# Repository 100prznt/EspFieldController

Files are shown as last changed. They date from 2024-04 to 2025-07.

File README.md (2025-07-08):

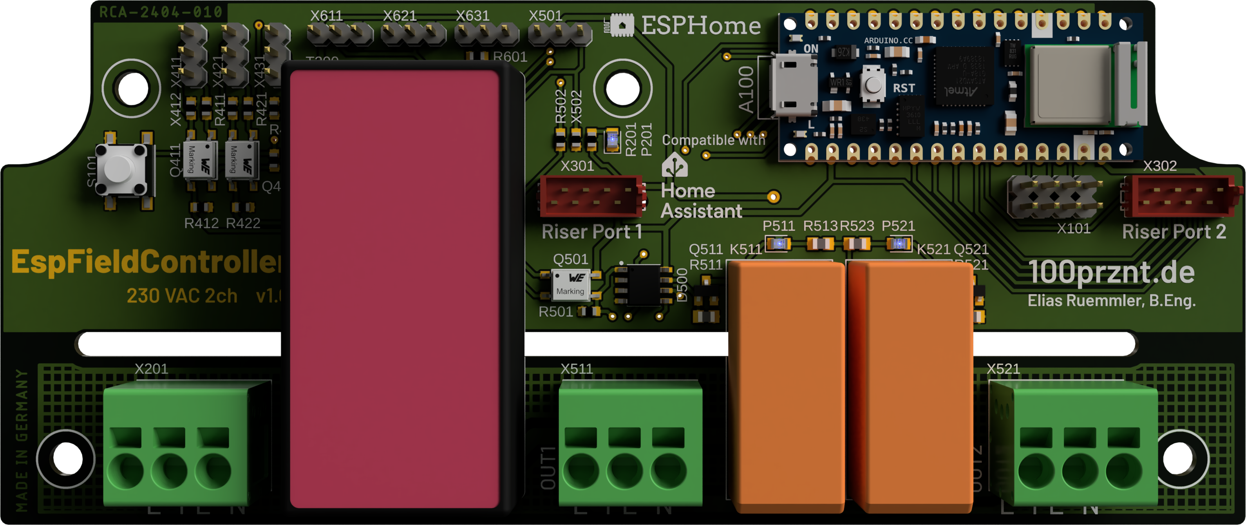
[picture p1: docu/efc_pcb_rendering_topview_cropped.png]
CAD rendering EspFieldController PCB


# ESP Field Controller
Modular aufgebauter Hardware-Controller für den Betrieb mit ESPHome.

Mit dem **ESP Field Controller** möchte ich eine Hardwarebasis für den Einsatz von ESPHome im "Außenbereich", also zumindest außerhab von Wohnräumen, schaffen. Eine wichtige Anforderung ist hier natürlich die [Schutzart](https://de.wikipedia.org/wiki/Schutzart). Daher wird der Controller in ein entsprechnd klassifiziertes Gehäuse montiert und verfügt auch über ein eigenes Netzteil. Basisfunktionalität, welche sehr oft benötigt wird, bringt der Controller selber mit. Für Anwendungen, welche etwas speziellere Features benötigen, lässt sich der Controller modular erweitern.

## Projektstatus
Nach einem ersten Prototyp-Aufbau auf dem Breadboard, folgt nun die erste PCB Revision. Hier ein fertiger **EspFieldController** mit gebrückter *Safety Circuit* und [WaterAnalyticRiser](WaterAnalyticRiser) *(WAR)*.

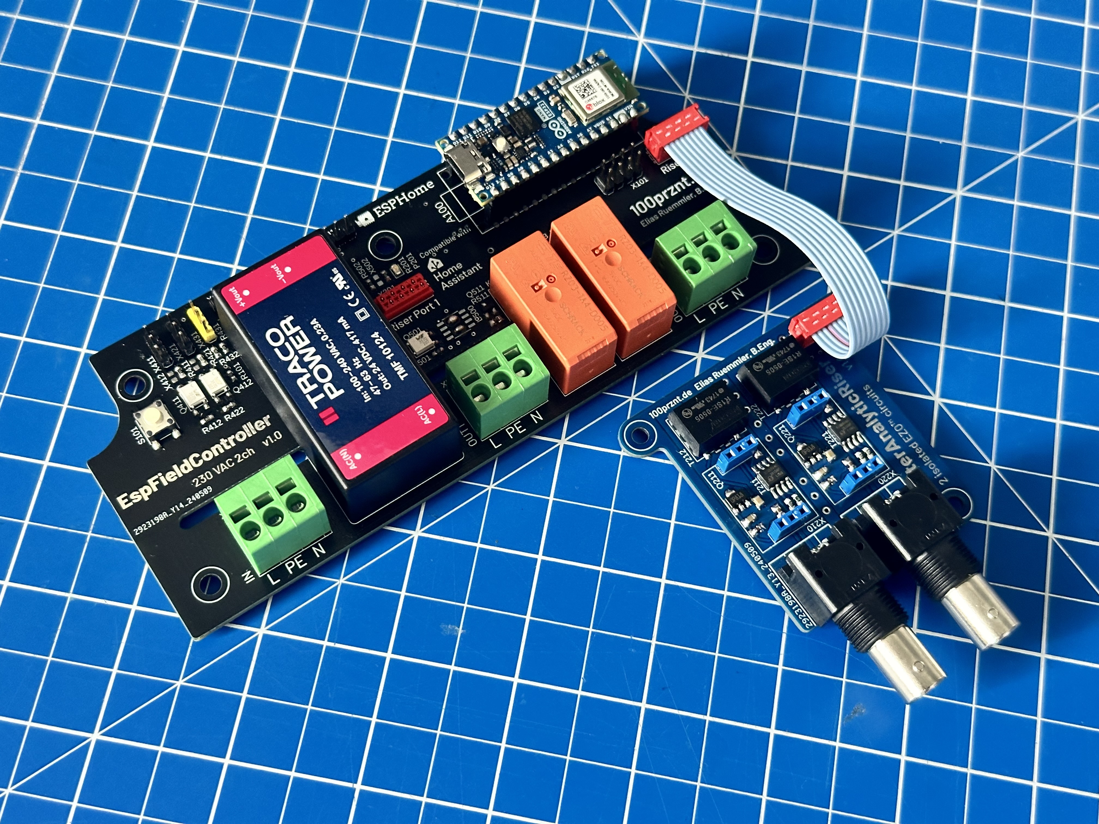
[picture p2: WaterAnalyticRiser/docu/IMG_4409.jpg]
Aufgebauter EspFieldController mit Water Analytic Riser


## Basisfunktionen

### Netzteil
* 230 VAC Netzklemme
* Versorgung von Arduino Nano ESP32 und Peripherie
* 5 VDC (VIN)
#### Auf Arduino Nano ESP32
* Schutzdiode zwischen USB und VIN
* 3,3 VDC über linearen Spannungsregler

### Eingänge
* 2 digitale Eingänge, per Optokoppler Isoliert (Spannung kann über Widerstandsnetzwerk individuell festgelegt werden)
* 1 digitaler Freigabeeingang für Safety Circuit, per Optokoppler Isoliert (Spannung kann über Widerstandsnetzwerk individuell festgelegt werden)
* 1 analoger Eingang (Spannungsbereich kann über Widerstandsnetzwerk individuell festgelegt werden)
* 1 Taster

### Ausgänge

#### Relais
* 2 unabhängige Kanäle
* 230 VAC 10 A (einpolig, Summenstrom nicht über 10 A)
* 230 VAC Eingang über Netzklemme, L, N, PE (welche auch das Netzteil versorgt)
* Ausgangsklemmen inkl. N und PE
##### Safety Circuit
* Optional per eigenen Controller (alternativ per 0R gebrückt)
* ATtiny25 (SOIC)
* Softwarefunktionen
  * Überwachung des ESP per Watchdog
  * Externe Freigabe per Enable Eingang (isoliert)
  * Verriegelung der Kanäle (inkl. Definition von Umschaltzeiten)
 
###### Pinning
| Pin | Port | ATtiny25 | Funktion |
|-----|---|---|---|
| 1 | PB5  | PCINT5/RESET/ADC0/dW | Ext. Enable |
| 2 | PB3  | PCINT3/XTAL1/CLKI/OC1B/ADC3 | Ch1 Enable  |
| 3 | PB4  | PCINT4/XTAL2/CLKO/OC1B/ADC2 | Ch2 Enable  |
| 4 | GND  | | |
| 5 | PB0  | MOSI/DI/SDA/AIN0/OC0A/OC1A/AREF/PCINT0 | Watchdog |
| 6 | PB1  | MISO/DO/AIN1/OC0B/OC1A/PCINT1 | Ch2 Out |
| 7 | PB2  | SCK/USCK/SCL/ADC1/T0/INT0/PCINT2 | Ch1 Out |
| 8 | VCC  | | |

### 1-Wire
* 3 Stecker auf einem Bus (2,54 mm Stiftleiste)

## Riser
Zur modularen Erweiterung können an den _EspFiledController_ bis zu zwei _Riser Boards_ angeschlossen werden.
* [WAR - Water Analytic Riser](/WaterAnalyticRiser)
* [LCR - LoadCellRiser](/LoadCellRiser)

### Riser-Ports

#### Pinning Micro-Match
| Pin | | Funktion | GPIO |
|-----|---|---|---|
| 1  | Supply | +5 V | |
| 2  | Supply | +3.3 V | |
| 3  | IO | EXT1_IO1 | |
| 4  | IO | EXT2_IO2 | |
| 5  | I2C | SDA | GPIO11 |
| 6  | I2C | SCL | GPIO12 |
| 7  | 1-Wire | Data | GPIO5  |
| 8  | | GND | |

### ESP Board
* Arduino Nano ESP32 (NORA-W106-10B [ESP32-S3])
* Alternative (low-cost) Boards per individueller PCB (mapping auf Nano Footprint) 

#### Pinning
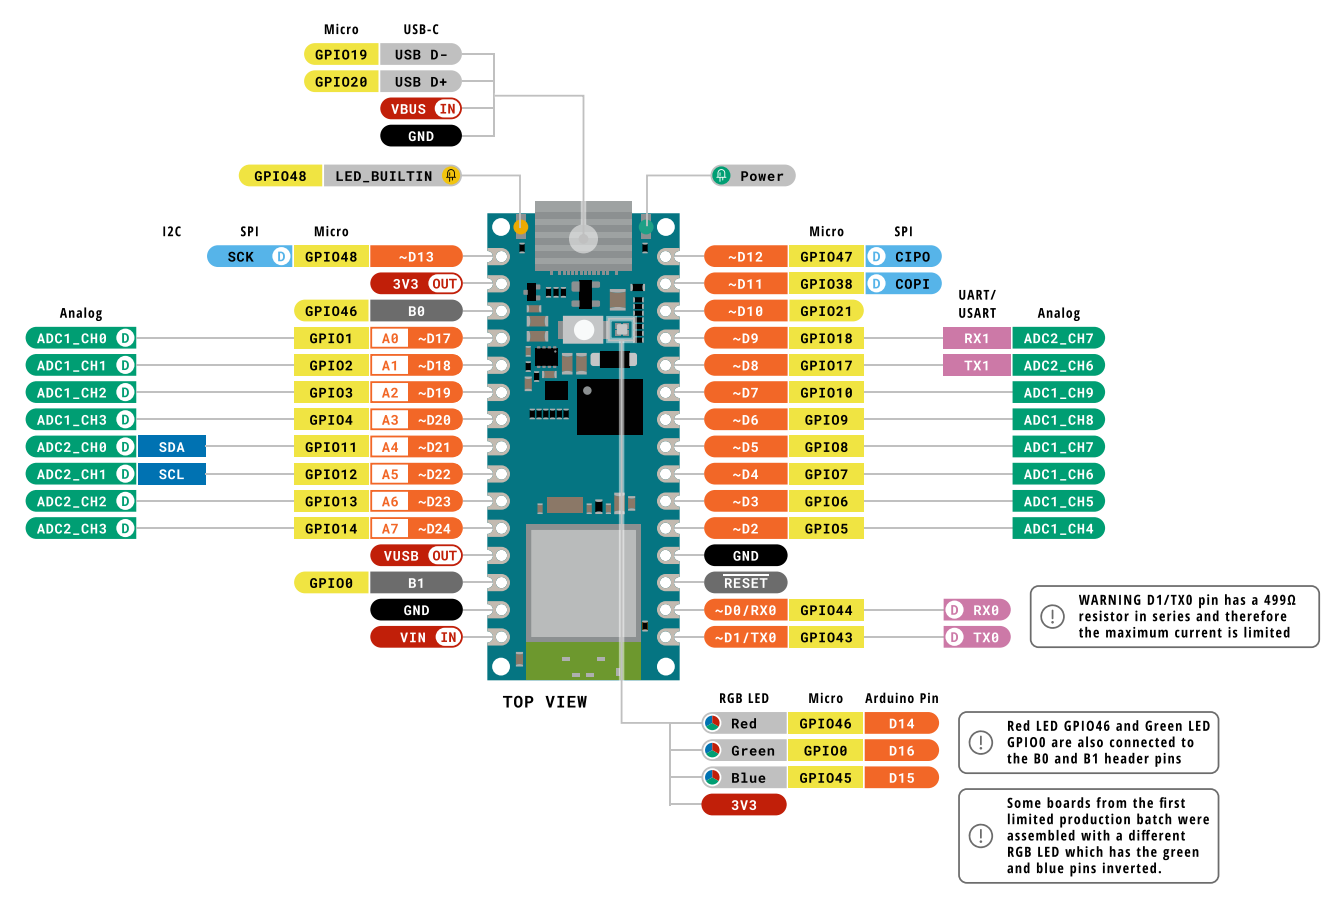
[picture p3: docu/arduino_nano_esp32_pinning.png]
Pinning Arduino Nano ESP32


## GPIO Zuordnung
| GPIO | Funktion | Funktionseinheit | Beschreibung |
|---|---|---|---|
| 0 | LED green | | |
| 1 | | EXT1 | |
| 2 | | EXT1 | |
| 3 | | EXT2 | |
| 4 | | EXT2 | |
| 5 | | 1-Wire | |
| 6 | | Taster | |
| 7 | | Relais | IN EN |
| 8 | | Relais | OUT Watchdog |
| 9 | | Relais | OUT CH1 |
| 10 | | Relais | OUT CH2 |
| 11 | I2C SDA | EXT1 u. EXT2 | |
| 12 | I2C SCL | EXT1 u. EXT2 | |
| 13 | | Eingang | |
| 14 | | Eingang | |
| 17 | | Analogeingang | |
| 18 | | | |
| 21 | | | |
| 38 | SPI COPI | | |
| 43 | UART RX0 | | |
| 44 | UART TX0 | | |
| 45 | LED blue | | |
| 46 | LED red | | |
| 47 | SPI CIPO | | |
| 48 | SPI SCK; LED_BUILDIN | | |

#### Standardpins
| ~D | GPIO | I2C | SPI |
|----|---|-----|---|
| 21 | 11 | SDA | |
| 22 | 12 | SCL | |
| 10 | 21 | | CS |
| 11 | 38 | | COPI (MOSI) |
| 12 | 47 | | CIPO (MISO) |
| 13 | 48 | | SCK |

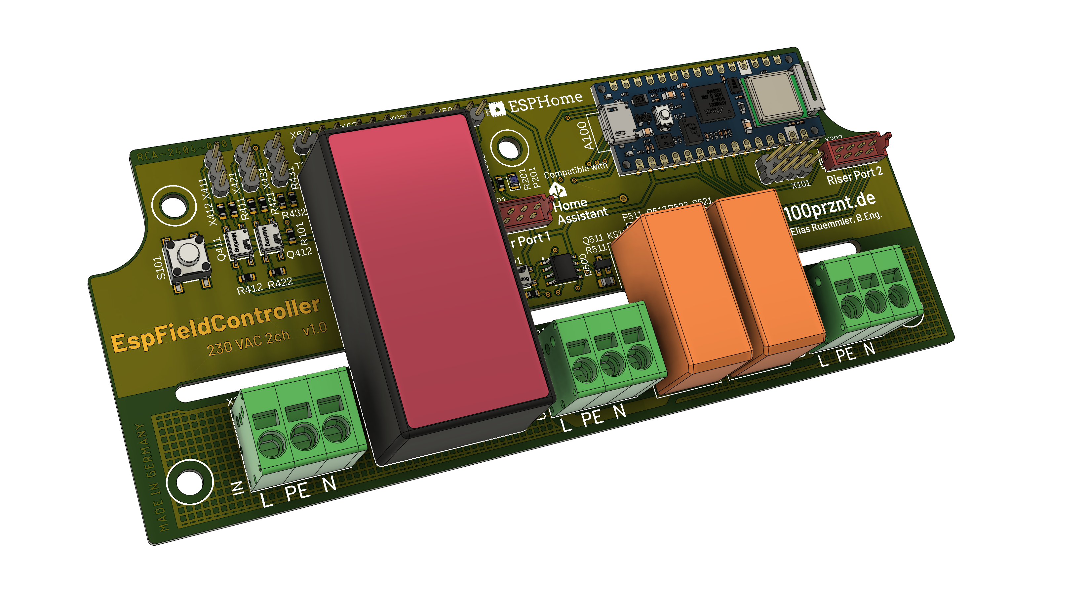
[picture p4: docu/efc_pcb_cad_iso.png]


## Feature Request (next version)
* Relais überwachen
  - Stromüberwachung
  - Sicherheitsrelais
* Rückmeldung Safety Cricuit an ESP

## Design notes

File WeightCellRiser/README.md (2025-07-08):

# Load Cell Riser :mag:

Erweitert den [ESP Field Controller](../) um zwei NAU7802 24-bit ADCs, an welche Wägezellen oder -sensoren angeschlossen werden können.

### NAU7802
Adafruit - NAU7802 24-bit ADC

* [ESPHome - NAU7802](https://esphome.io/components/sensor/nau7802)
* [I2C Mux](https://esphome.io/components/tca9548a)

### Notes
* [SparkFun - Load Cell Amplifier HX711 Breakout Hookup Guide](https://learn.sparkfun.com/tutorials/load-cell-amplifier-hx711-breakout-hookup-guide)
* [SparkFun - Load Cell Combinator - Schematics](https://cdn.sparkfun.com/datasheets/Sensors/ForceFlex/SparkFun%20Load%20Sensor%20Combinator%20v11.pdf)

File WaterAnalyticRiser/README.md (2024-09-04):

# Water Analytic Riser :sweat_drops:

Erweitert den [ESP Field Controller](../) um zwei EZO Circuit Sockel, welche die entsprechenden Module von Atlas Scientifics aufnehmen können.

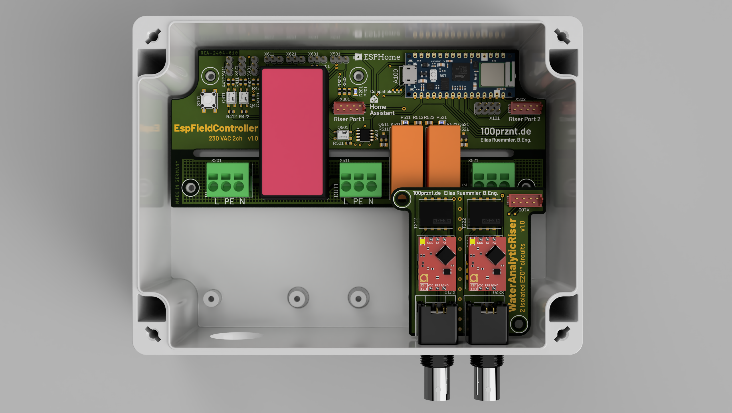
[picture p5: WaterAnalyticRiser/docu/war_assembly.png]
Zusammenbau im Spelsberg Gehäuse

_Der Water Analytic Riser findet zusammen mit dem ESP Field Controller im Spelsberg Industriegehäuse platz._

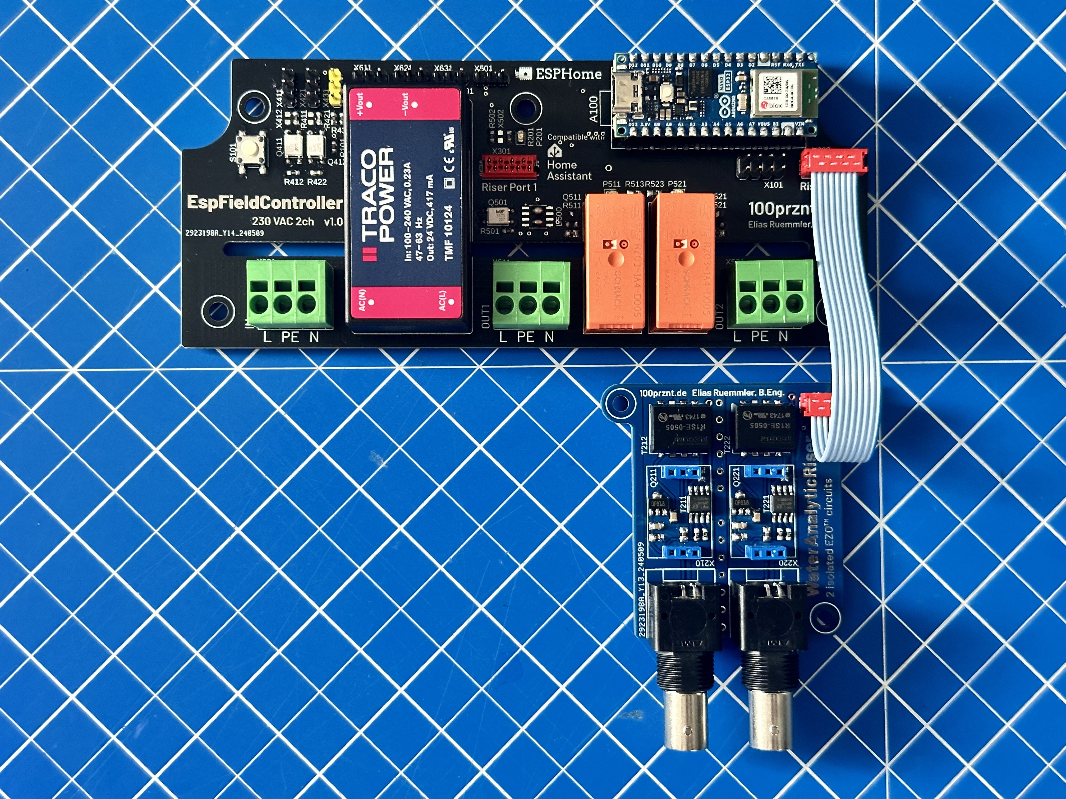
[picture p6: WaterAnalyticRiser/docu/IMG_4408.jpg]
Aufgebauter EspFieldController mit Water Analytic Riser


## Anwendung

Die Idee hinter dem __Water Analytic Riser__ ist der Aufbau einer automatischen Pool-Dosiersteuerung. Hierzu ist es erforderlich den __pH-Wert__ sowie das __Redoxpotential__ (ORP) messtechnisch zu erfassen und entsprechende __Dosierpumpen__ für Schwefelsäure (pH Senker) bzw. Natriumhypochlorit (Chlor) anzusteueren.
Über die ESPHome Konfiguration kann eine einfache Regelung eingerichtet werden, sodass die Dosierung der Chemie automatisch erfolgt und auch keine Host-Verbindung (Verbindung zu Home Assistant) erforderlich ist. Die entsprechenden Vorgabe- und Einstellwerte werden über Home Assistant konfiguriert und die Messwerte überwacht.

### Externe Hardware
* pH Elektrode
* Redox Elektrode
* Temperaturfühler (DS18B20) :link:
* Dosierpumpe für pH Senker :link:
* Dosierpumpe für Chlor :link:

:link: Anschluss am __ESP Field Controller__

## Funktionen

Um eine Potentialverschiebung an den eingesetzen Messelektroden zu vermeiden, ist sowohl die Versorgungsspannung als auch der I2C Bus für jedes EZO Circuit isoliert ausgeführt. Die herausgeführten Elektrodenanschlüsse sind somit gegeneinander und gegen den ESP Field Controller isoliert, sowohl auf der Messleitung also auch auf der zugehörigen Masse.

* Isolierte Versorgungsspannung je EZO Sockel
* Isolierter I2C Bus je EZO Sockel

## Feature Request

* 1-Wire Stecker für DS18B20
* Taster für Kalibrierung
* Linear geregelte Spannungsversorgung (low noise)
* Versorgunsspannung schaltbar (stand-by)

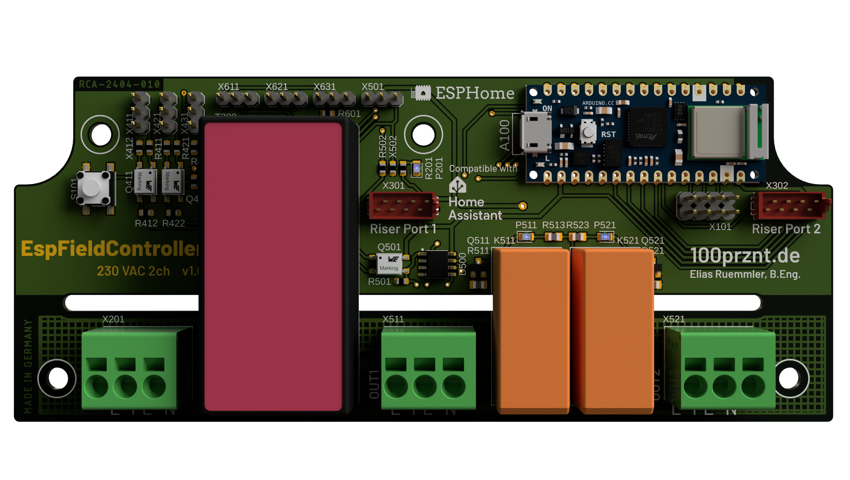
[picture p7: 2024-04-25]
docu/efc_pcb_rendering_topview.png

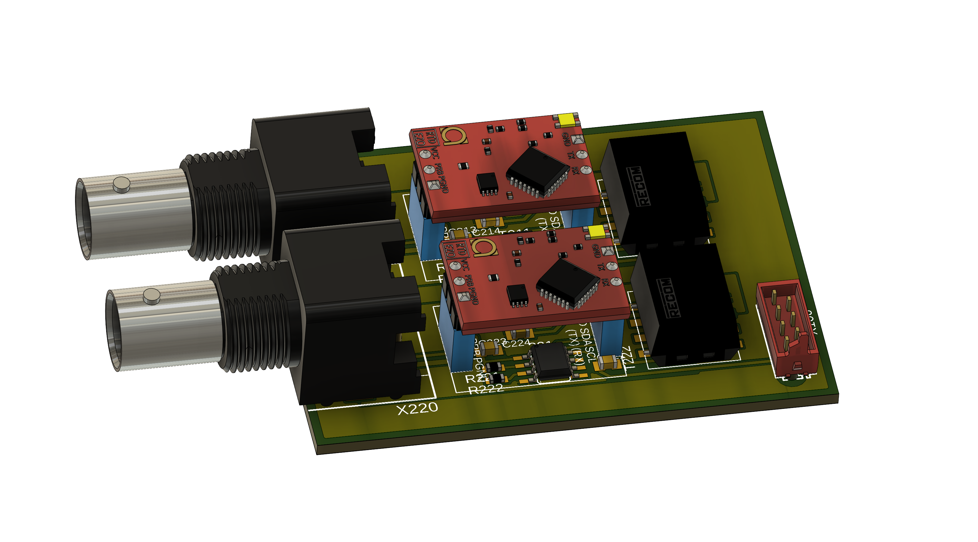
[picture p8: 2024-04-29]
WaterAnalyticRiser/docu/war_pcb_cad_iso_beta.png

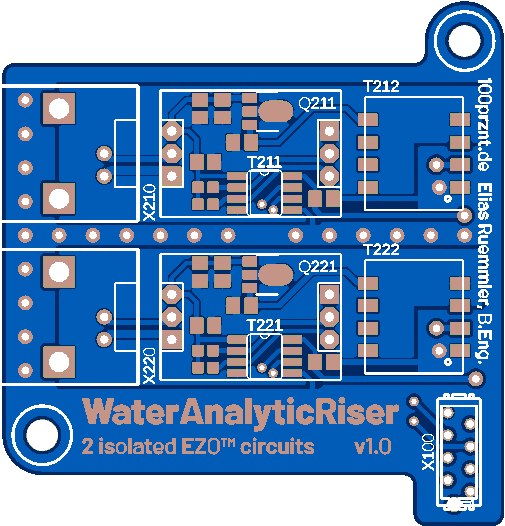
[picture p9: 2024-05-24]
WaterAnalyticRiser/production/JLCPCB_GerberView.png

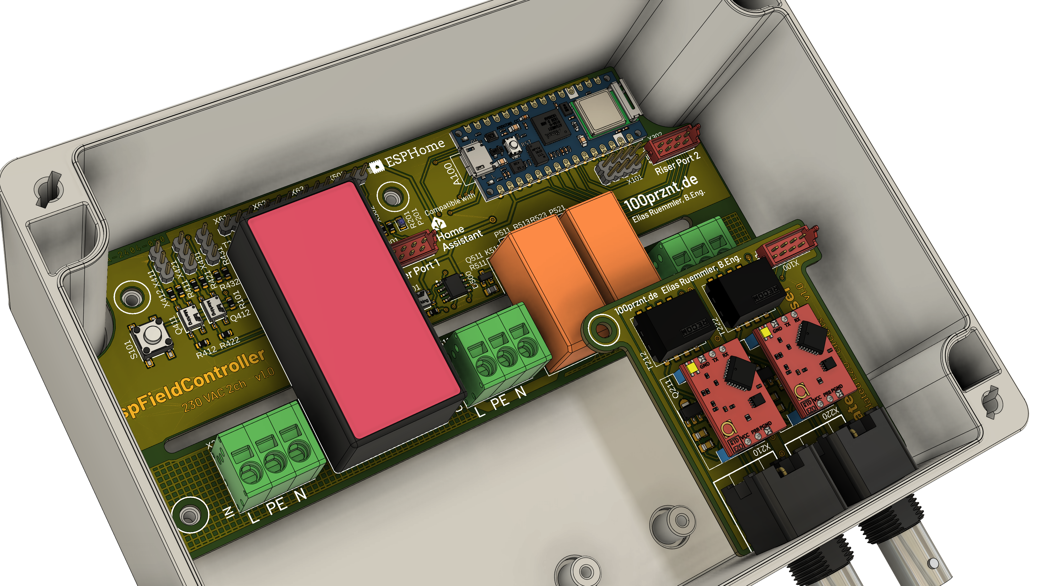
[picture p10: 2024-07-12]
WaterAnalyticRiser/docu/war_asy_cad_iso.png

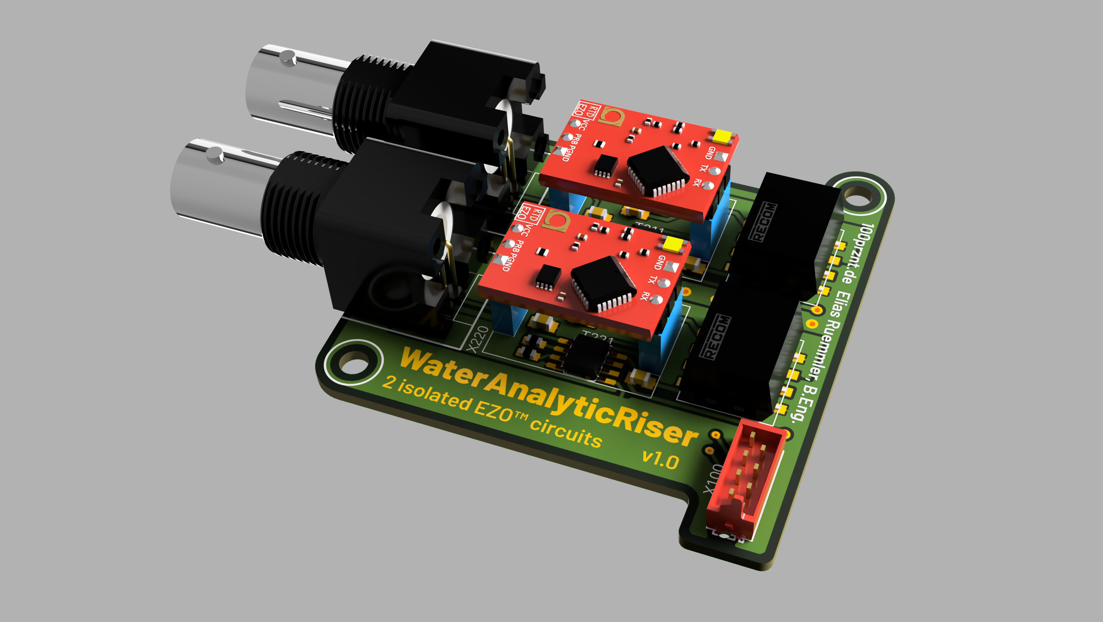
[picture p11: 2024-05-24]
WaterAnalyticRiser/docu/war_pcb_redering_iso.png

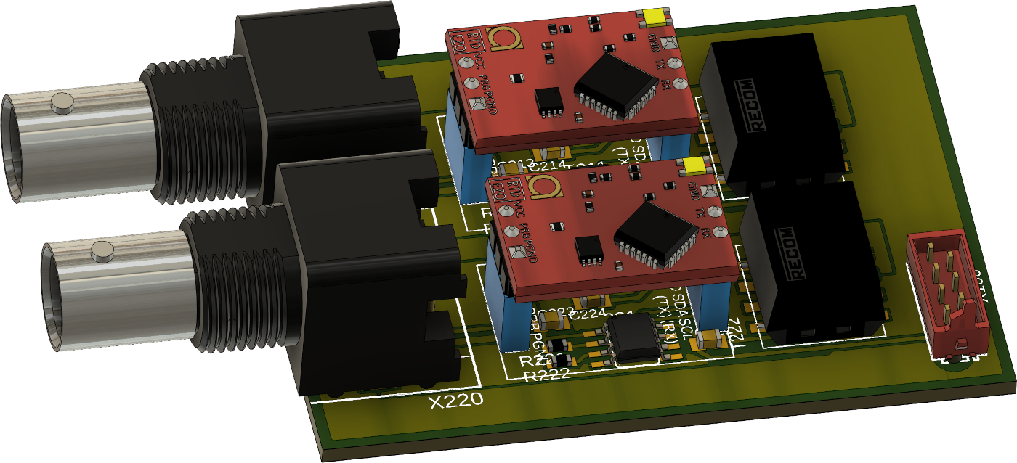
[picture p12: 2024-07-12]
WaterAnalyticRiser/docu/war_pcb_cad_iso_beta_cropped_resized.png

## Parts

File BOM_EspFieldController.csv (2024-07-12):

Part | Value | Device | Package | Description | ARROW_PART_NUMBER | ARROW_PRICE-STOCK | BUILT_BY | CATEGORY | COLOR | COPYRIGHT | CORE | CTR-MAX | CTR-MIN | DATASHEET-URL | DESCRIPTION | DRAIN_CURRENT | FORWARD_CURRENT | HEIGHT | IF | MANUFACTURER | MANUFACTURER_NAME | MANUFACTURER_PART_NUMBER | MF | MOUNT | MOUSER_PART_NUMBER | MOUSER_PRICE-STOCK | MPN | OC_FARNELL | OC_NEWARK | OPERATING_TEMP | OPERATION-FORCE | PART-NUMBER | PART_STATUS | POPULARITY | QTY | REVERSE_VOLTAGE | ROHS_COMPLIANT | SERIES | SPEED | SPICEPREFIX | SUB-CATEGORY | TC-CTR | THERMALLOSS | TYPE | VALUE | VCE | VENDOR | VISO
A100 | Arduino Nano ESP32 | NANO_ESP32 | NANO |  |  |  |  |  |  |  |  |  |  |  |  |  |  |  |  |  |  |  |  |  |  |  |  |  |  |  |  |  |  |  |  |  |  |  |  |  |  |  |  |  | Arduino Nano ESP32
D500 | ATtiny25-20SSH | ATTINY25-20SSH-8PIN_SOIC | SOIC127P600X175-8N | Atmel tiny25/45/85, 8-bit AVR Microcontroller with 2/4/8K |  |  |  | IC_Embedded |  |  | AVR |  |  |  | AVR AVR� ATtiny, Functional Safety (FuSa) Microcontroller IC 8-Bit 20MHz 2KB (1K x 16) FLASH 8-SOIC |  |  |  |  | Microchip Technology |  |  |  |  |  |  | ATtiny25-20SSH |  |  | -40�C to 85�C |  |  | Active |  |  |  | COMPLIANT | ATtiny25 | 20 MHz |  | Microcontroller |  |  | 8 bit Microcontroller | ATtiny25-20SSH
K511 | RZ03-1A4-D005 | 1-1415899-6 | RELAY-SPST2_5MM |  |  |  | EMA_UL_Team | Power Relays |  | Copyright (C) 2016 Accelerated Designs. All rights reserved |  |  |  |  | RZ03-1A4-D012 |  |  |  |  |  |  | 1-1415899-6 |  |  |  |  |  |  |  |  |  |  | active |  |  |  |  | SCHRACK Power PCB Relay RZ |  |  |  |  |  |  |  |  | TE Connectivity
K521 | RZ03-1A4-D005 | 1-1415899-6 | RELAY-SPST2_5MM |  |  |  | EMA_UL_Team | Power Relays |  | Copyright (C) 2016 Accelerated Designs. All rights reserved |  |  |  |  | RZ03-1A4-D012 |  |  |  |  |  |  | 1-1415899-6 |  |  |  |  |  |  |  |  |  |  | active |  |  |  |  | SCHRACK Power PCB Relay RZ |  |  |  |  |  |  |  |  | TE Connectivity
P201 | LED_BLUE | CHIP-FLAT-B_0805 | LEDC2012X110N_FLAT-B |  |  |  |  | LED | BLUE |  |  |  |  |  | CHIP LED FLAT |  |  |  |  |  |  |  |  |  |  |  |  |  |  |  |  |  |  |  |  |  |  |  |  |  | CHIP |  |  | FLAT_TOP | LED_BLUE
P511 | LED_BLUE | CHIP-FLAT-B_0805 | LEDC2012X110N_FLAT-B |  |  |  |  | LED | BLUE |  |  |  |  |  | CHIP LED FLAT |  |  |  |  |  |  |  |  |  |  |  |  |  |  |  |  |  |  |  |  |  |  |  |  |  | CHIP |  |  | FLAT_TOP | LED_BLUE
P521 | LED_BLUE | CHIP-FLAT-B_0805 | LEDC2012X110N_FLAT-B |  |  |  |  | LED | BLUE |  |  |  |  |  | CHIP LED FLAT |  |  |  |  |  |  |  |  |  |  |  |  |  |  |  |  |  |  |  |  |  |  |  |  |  | CHIP |  |  | FLAT_TOP | LED_BLUE
Q411 | 140357145400 | WL-OCPT_SERIES_357_140357145400 | WL-OCPT_SOP4 | WL-OCPT SOP-4 |  |  |  |  |  |  |  | 600% | 300% | https://www.we-online.com/redexpert/spec/140357145400?ae |  |  |  |  | 60mA |  |  |  |  | SMT |  |  |  |  |  |  |  | 140357145400 |  |  |  |  |  |  |  |  |  | IF = 5mA,VCE = 5 V |  |  | 140357145400 | 35V |  | 3750(V(RMS))
Q412 | 140357145400 | WL-OCPT_SERIES_357_140357145400 | WL-OCPT_SOP4 | WL-OCPT SOP-4 |  |  |  |  |  |  |  | 600% | 300% | https://www.we-online.com/redexpert/spec/140357145400?ae |  |  |  |  | 60mA |  |  |  |  | SMT |  |  |  |  |  |  |  | 140357145400 |  |  |  |  |  |  |  |  |  | IF = 5mA,VCE = 5 V |  |  | 140357145400 | 35V |  | 3750(V(RMS))
Q501 | 140357145400 | WL-OCPT_SERIES_357_140357145400 | WL-OCPT_SOP4 | WL-OCPT SOP-4 |  |  |  |  |  |  |  | 600% | 300% | https://www.we-online.com/redexpert/spec/140357145400?ae |  |  |  |  | 60mA |  |  |  |  | SMT |  |  |  |  |  |  |  | 140357145400 |  |  |  |  |  |  |  |  |  | IF = 5mA,VCE = 5 V |  |  | 140357145400 | 35V |  | 3750(V(RMS))
Q511 | BSS138 | NMOSFETSOT23-GSD | SOT23 | N-Channel MOSFET - Generic |  |  |  | Transistor |  |  |  |  |  |  |  |  |  |  |  |  |  |  |  |  |  |  |  |  |  |  |  |  |  |  |  |  |  |  |  |  | MOSFET |  |  | N-Channel | NMOSFET
Q521 | BSS138 | NMOSFETSOT23-GSD | SOT23 | N-Channel MOSFET - Generic |  |  |  | Transistor |  |  |  |  |  |  |  |  |  |  |  |  |  |  |  |  |  |  |  |  |  |  |  |  |  |  |  |  |  |  |  |  | MOSFET |  |  | N-Channel | NMOSFET
R101 | 10K | R-EU_R0603 | R0603 | RESISTOR, European symbol |  |  |  |  |  |  |  |  |  |  |  |  |  |  |  |  |  |  |  |  |  |  |  |  |  |  |  |  |  | 70 |  |  |  |  |  | R
R201 | 500R | R-EU_R0603 | R0603 | RESISTOR, European symbol |  |  |  |  |  |  |  |  |  |  |  |  |  |  |  |  |  |  |  |  |  |  |  |  |  |  |  |  |  | 70 |  |  |  |  |  | R
R411 | 500R | R-EU_R0603 | R0603 | RESISTOR, European symbol |  |  |  |  |  |  |  |  |  |  |  |  |  |  |  |  |  |  |  |  |  |  |  |  |  |  |  |  |  | 70 |  |  |  |  |  | R
R412 | 500R | R-EU_R0603 | R0603 | RESISTOR, European symbol |  |  |  |  |  |  |  |  |  |  |  |  |  |  |  |  |  |  |  |  |  |  |  |  |  |  |  |  |  | 70 |  |  |  |  |  | R
R421 | 500R | R-EU_R0603 | R0603 | RESISTOR, European symbol |  |  |  |  |  |  |  |  |  |  |  |  |  |  |  |  |  |  |  |  |  |  |  |  |  |  |  |  |  | 70 |  |  |  |  |  | R
R422 | 500R | R-EU_R0603 | R0603 | RESISTOR, European symbol |  |  |  |  |  |  |  |  |  |  |  |  |  |  |  |  |  |  |  |  |  |  |  |  |  |  |  |  |  | 70 |  |  |  |  |  | R
R431 | 10K | R-EU_R0603 | R0603 | RESISTOR, European symbol |  |  |  |  |  |  |  |  |  |  |  |  |  |  |  |  |  |  |  |  |  |  |  |  |  |  |  |  |  | 70 |  |  |  |  |  | R
R432 | 10K | R-EU_R0603 | R0603 | RESISTOR, European symbol |  |  |  |  |  |  |  |  |  |  |  |  |  |  |  |  |  |  |  |  |  |  |  |  |  |  |  |  |  | 70 |  |  |  |  |  | R
R501 | 220 | R-EU_R0603 | R0603 | RESISTOR, European symbol |  |  |  |  |  |  |  |  |  |  |  |  |  |  |  |  |  |  |  |  |  |  |  |  |  |  |  |  |  | 70 |  |  |  |  |  | R
R502 | 220 | R-EU_R0603 | R0603 | RESISTOR, European symbol |  |  |  |  |  |  |  |  |  |  |  |  |  |  |  |  |  |  |  |  |  |  |  |  |  |  |  |  |  | 70 |  |  |  |  |  | R
R511 | 47K | R-EU_R0805 | R0805 | RESISTOR, European symbol |  |  |  |  |  |  |  |  |  |  |  |  |  |  |  |  |  |  |  |  |  |  |  |  |  |  |  |  |  | 86 |  |  |  |  |  | R
R512 | 1N4148W | DIODE_1N4148W-7-F_SOD123G | SOD3715X135 | Diode Rectifier - Popular parts |  |  |  | Diode |  |  |  |  |  |  | DIODE GEN PURP 100V 300MA SOD123 |  |  |  |  | Diodes Incorporated |  |  |  |  |  |  |  |  |  |  |  |  |  |  |  |  |  |  |  |  | Rectifier |  |  |  | 1N4148W
R513 | 220 | R-EU_R0805 | R0805 | RESISTOR, European symbol |  |  |  |  |  |  |  |  |  |  |  |  |  |  |  |  |  |  |  |  |  |  |  |  |  |  |  |  |  | 86 |  |  |  |  |  | R
R521 | 47K | R-EU_R0805 | R0805 | RESISTOR, European symbol |  |  |  |  |  |  |  |  |  |  |  |  |  |  |  |  |  |  |  |  |  |  |  |  |  |  |  |  |  | 86 |  |  |  |  |  | R
R522 | 1N4148W | DIODE_1N4148W-7-F_SOD123G | SOD3715X135 | Diode Rectifier - Popular parts |  |  |  | Diode |  |  |  |  |  |  | DIODE GEN PURP 100V 300MA SOD123 |  |  |  |  | Diodes Incorporated |  |  |  |  |  |  |  |  |  |  |  |  |  |  |  |  |  |  |  |  | Rectifier |  |  |  | 1N4148W
R523 | 220 | R-EU_R0805 | R0805 | RESISTOR, European symbol |  |  |  |  |  |  |  |  |  |  |  |  |  |  |  |  |  |  |  |  |  |  |  |  |  |  |  |  |  | 86 |  |  |  |  |  | R
R601 | 10K | R-EU_R0603 | R0603 | RESISTOR, European symbol |  |  |  |  |  |  |  |  |  |  |  |  |  |  |  |  |  |  |  |  |  |  |  |  |  |  |  |  |  | 70 |  |  |  |  |  | R
S101 | 430152050826 | 430152050826 | 430152050826 | WS-TASV SMT Tact Switch 6x6 mm |  |  |  |  |  |  |  |  |  | https://www.we-online.com/redexpert/spec/430152050826?ae |  |  |  | 5mm |  |  |  |  |  |  |  |  |  |  |  |  | 260g | 430152050826 |  |  | 1000 |  |  |  |  |  |  |  |  |  | 430152050826
T200 | TMF 10105 | TMF_101 | TMF10
X101 |  | PINHD-2X4 | 2X04 | PIN HEADER |  |  |  |  |  |  |  |  |  |  |  |  |  |  |  |  |  |  |  |  |  |  |  |  |  |  |  |  |  | 47
X201 | SPT2,5/3-V-5,0 | SPT2,5/3-V-5,0 | SPT2,5/3-V-5,0 | SPT 2,5/ 3-V-5,0 | 1991105 | https://www.arrow.com/en/products/1991105/phoenix-contact?region=nac |  |  |  |  |  |  |  |  | PCB terminal block, nominal current: 24 A, rated voltage (III/2): 400 V, nominal cross section: 2.5 mm?, Number of potentials: 3, Number of rows: 1, Number of positions per row: 3, product range: SPT 2,5/..-V, pitch: 5 mm, connection method: Push-in spring connection, mounting: Wave soldering, conductor/PCB connection direction: 90 ?, color: green, Pin layout: Linear double pinning, Solder pin [P]: 2.5 mm, type of packaging: packed in cardboard |  |  | 14.4mm |  |  | Phoenix Contact | 1991105 |  |  | 651-1991105 | https://www.mouser.co.uk/ProductDetail/Phoenix-Contact/1991105?qs=HG6crFoccqodg51MDMYEiw%3D%3D
X301 | MICROMATCH-8 | MICROMATCH-8 | MICROMATCH-8 | MicroMaTch 8 7-215464-8 / 0-215464-8 |  |  |  |  |  |  |  |  |  |  |  |  |  |  |  |  |  |  | FARNELL |  |  |  | 7-215464-8 | 3784642 | 26H0301
X302 | MICROMATCH-8 | MICROMATCH-8 | MICROMATCH-8 | MicroMaTch 8 7-215464-8 / 0-215464-8 |  |  |  |  |  |  |  |  |  |  |  |  |  |  |  |  |  |  | FARNELL |  |  |  | 7-215464-8 | 3784642 | 26H0301
X411 |  | PINHD-1X3 | 1X03 | PIN HEADER |  |  |  |  |  |  |  |  |  |  |  |  |  |  |  |  |  |  |  |  |  |  |  |  |  |  |  |  |  | 92
X412 | n/a | R-EU_R0603 | R0603 | RESISTOR, European symbol |  |  |  |  |  |  |  |  |  |  |  |  |  |  |  |  |  |  |  |  |  |  |  |  |  |  |  |  |  | 70 |  |  |  |  |  | R
X421 |  | PINHD-1X3 | 1X03 | PIN HEADER |  |  |  |  |  |  |  |  |  |  |  |  |  |  |  |  |  |  |  |  |  |  |  |  |  |  |  |  |  | 92
X422 | n/a | R-EU_R0603 | R0603 | RESISTOR, European symbol |  |  |  |  |  |  |  |  |  |  |  |  |  |  |  |  |  |  |  |  |  |  |  |  |  |  |  |  |  | 70 |  |  |  |  |  | R
X431 |  | PINHD-1X3 | 1X03 | PIN HEADER |  |  |  |  |  |  |  |  |  |  |  |  |  |  |  |  |  |  |  |  |  |  |  |  |  |  |  |  |  | 92
X501 |  | PINHD-1X3 | 1X03 | PIN HEADER |  |  |  |  |  |  |  |  |  |  |  |  |  |  |  |  |  |  |  |  |  |  |  |  |  |  |  |  |  | 92
X502 | n/a | R-EU_R0603 | R0603 | RESISTOR, European symbol |  |  |  |  |  |  |  |  |  |  |  |  |  |  |  |  |  |  |  |  |  |  |  |  |  |  |  |  |  | 70 |  |  |  |  |  | R
X511 | SPT2,5/3-V-5,0 | SPT2,5/3-V-5,0 | SPT2,5/3-V-5,0 | SPT 2,5/ 3-V-5,0 | 1991105 | https://www.arrow.com/en/products/1991105/phoenix-contact?region=nac |  |  |  |  |  |  |  |  | PCB terminal block, nominal current: 24 A, rated voltage (III/2): 400 V, nominal cross section: 2.5 mm?, Number of potentials: 3, Number of rows: 1, Number of positions per row: 3, product range: SPT 2,5/..-V, pitch: 5 mm, connection method: Push-in spring connection, mounting: Wave soldering, conductor/PCB connection direction: 90 ?, color: green, Pin layout: Linear double pinning, Solder pin [P]: 2.5 mm, type of packaging: packed in cardboard |  |  | 14.4mm |  |  | Phoenix Contact | 1991105 |  |  | 651-1991105 | https://www.mouser.co.uk/ProductDetail/Phoenix-Contact/1991105?qs=HG6crFoccqodg51MDMYEiw%3D%3D
X512 | n/a | R-EU_R0603 | R0603 | RESISTOR, European symbol |  |  |  |  |  |  |  |  |  |  |  |  |  |  |  |  |  |  |  |  |  |  |  |  |  |  |  |  |  | 70 |  |  |  |  |  | R
X521 | SPT2,5/3-V-5,0 | SPT2,5/3-V-5,0 | SPT2,5/3-V-5,0 | SPT 2,5/ 3-V-5,0 | 1991105 | https://www.arrow.com/en/products/1991105/phoenix-contact?region=nac |  |  |  |  |  |  |  |  | PCB terminal block, nominal current: 24 A, rated voltage (III/2): 400 V, nominal cross section: 2.5 mm?, Number of potentials: 3, Number of rows: 1, Number of positions per row: 3, product range: SPT 2,5/..-V, pitch: 5 mm, connection method: Push-in spring connection, mounting: Wave soldering, conductor/PCB connection direction: 90 ?, color: green, Pin layout: Linear double pinning, Solder pin [P]: 2.5 mm, type of packaging: packed in cardboard |  |  | 14.4mm |  |  | Phoenix Contact | 1991105 |  |  | 651-1991105 | https://www.mouser.co.uk/ProductDetail/Phoenix-Contact/1991105?qs=HG6crFoccqodg51MDMYEiw%3D%3D
X522 | n/a | R-EU_R0603 | R0603 | RESISTOR, European symbol |  |  |  |  |  |  |  |  |  |  |  |  |  |  |  |  |  |  |  |  |  |  |  |  |  |  |  |  |  | 70 |  |  |  |  |  | R
X611 |  | PINHD-1X3 | 1X03 | PIN HEADER |  |  |  |  |  |  |  |  |  |  |  |  |  |  |  |  |  |  |  |  |  |  |  |  |  |  |  |  |  | 92
X621 |  | PINHD-1X3 | 1X03 | PIN HEADER |  |  |  |  |  |  |  |  |  |  |  |  |  |  |  |  |  |  |  |  |  |  |  |  |  |  |  |  |  | 92
X631 |  | PINHD-1X3 | 1X03 | PIN HEADER |  |  |  |  |  |  |  |  |  |  |  |  |  |  |  |  |  |  |  |  |  |  |  |  |  |  |  |  |  | 92

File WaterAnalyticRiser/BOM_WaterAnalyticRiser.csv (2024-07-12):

Part | Value | Device | Package | Description | MF | MPN | OC_FARNELL | OC_NEWARK | POPULARITY | SPICEPREFIX | VALUE
C211 | 0u1 | C-EUC0805K | C0805K | CAPACITOR, European symbol |  |  |  |  | 52 | C
C212 | 0u1 | C-EUC0805K | C0805K | CAPACITOR, European symbol |  |  |  |  | 52 | C
C213 | 0u1 | C-EUC0805K | C0805K | CAPACITOR, European symbol |  |  |  |  | 52 | C
C214 | 1u | C-EUC0805K | C0805K | CAPACITOR, European symbol |  |  |  |  | 52 | C
C215 | 2u2 | C-EUC0805K | C0805K | CAPACITOR, European symbol |  |  |  |  | 52 | C
C221 | 0u1 | C-EUC0805K | C0805K | CAPACITOR, European symbol |  |  |  |  | 52 | C
C222 | 0u1 | C-EUC0805K | C0805K | CAPACITOR, European symbol |  |  |  |  | 52 | C
C223 | 0u1 | C-EUC0805K | C0805K | CAPACITOR, European symbol |  |  |  |  | 52 | C
C224 | 1u | C-EUC0805K | C0805K | CAPACITOR, European symbol |  |  |  |  | 52 | C
C225 | 2u2 | C-EUC0805K | C0805K | CAPACITOR, European symbol |  |  |  |  | 52 | C
Q211 | LD2981 | LD2981 | SOT89
Q221 | LD2981 | LD2981 | SOT89
R211 | 4K7 | R-EU_R0603 | R0603 | RESISTOR, European symbol |  |  |  |  | 70 | R
R212 | 4K7 | R-EU_R0603 | R0603 | RESISTOR, European symbol |  |  |  |  | 70 | R
R221 | 4K7 | R-EU_R0603 | R0603 | RESISTOR, European symbol |  |  |  |  | 70 | R
R222 | 4K7 | R-EU_R0603 | R0603 | RESISTOR, European symbol |  |  |  |  | 70 | R
T211 |  | SI8600 | SO08
T212 | RECOM_R1SE-0505 | RECOM_R1SE-0505 | R1SE_0505
T221 |  | SI8600 | SO08
T222 | RECOM_R1SE-0505 | RECOM_R1SE-0505 | R1SE_0505
U210 | pH Circuit | EZOSOCKET | EZO | EZO� Device |  |  |  |  |  |  | pH Circuit
U220 | pH Circuit | EZOSOCKET | EZO | EZO� Device |  |  |  |  |  |  | pH Circuit
X100 | MICROMATCH-8 | MICROMATCH-8 | MICROMATCH-8 | MicroMaTch 8 7-215464-8 / 0-215464-8 | FARNELL | 7-215464-8 | 3784642 | 26H0301
X210 | TE5227161 | TE5227161-9 | TE5227161 | BNC-Buchse |  |  |  |  |  |  | TE5227161
X220 | TE5227161 | TE5227161-9 | TE5227161 | BNC-Buchse |  |  |  |  |  |  | TE5227161

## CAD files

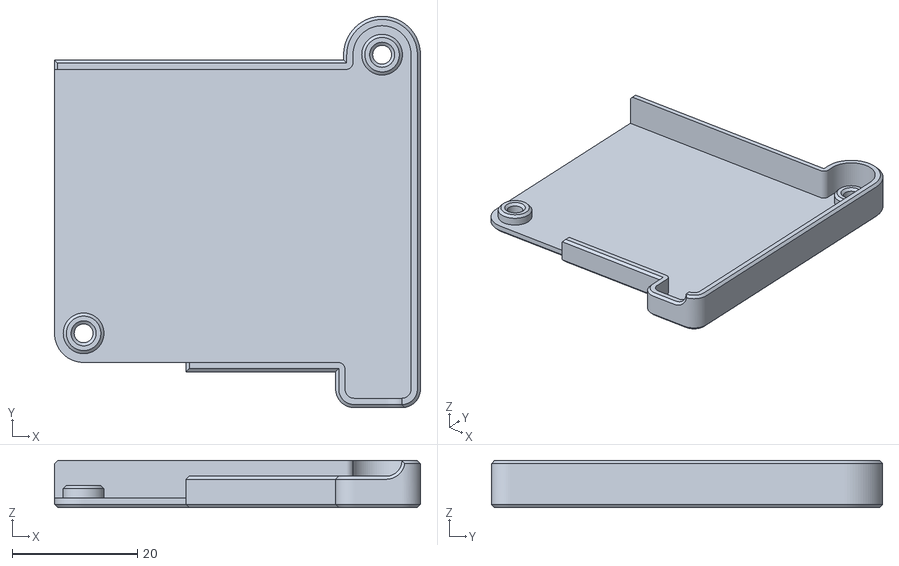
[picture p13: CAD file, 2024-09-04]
WaterAnalyticRiser/IsoCover.stl
58.4 x 62.4 x 7.50

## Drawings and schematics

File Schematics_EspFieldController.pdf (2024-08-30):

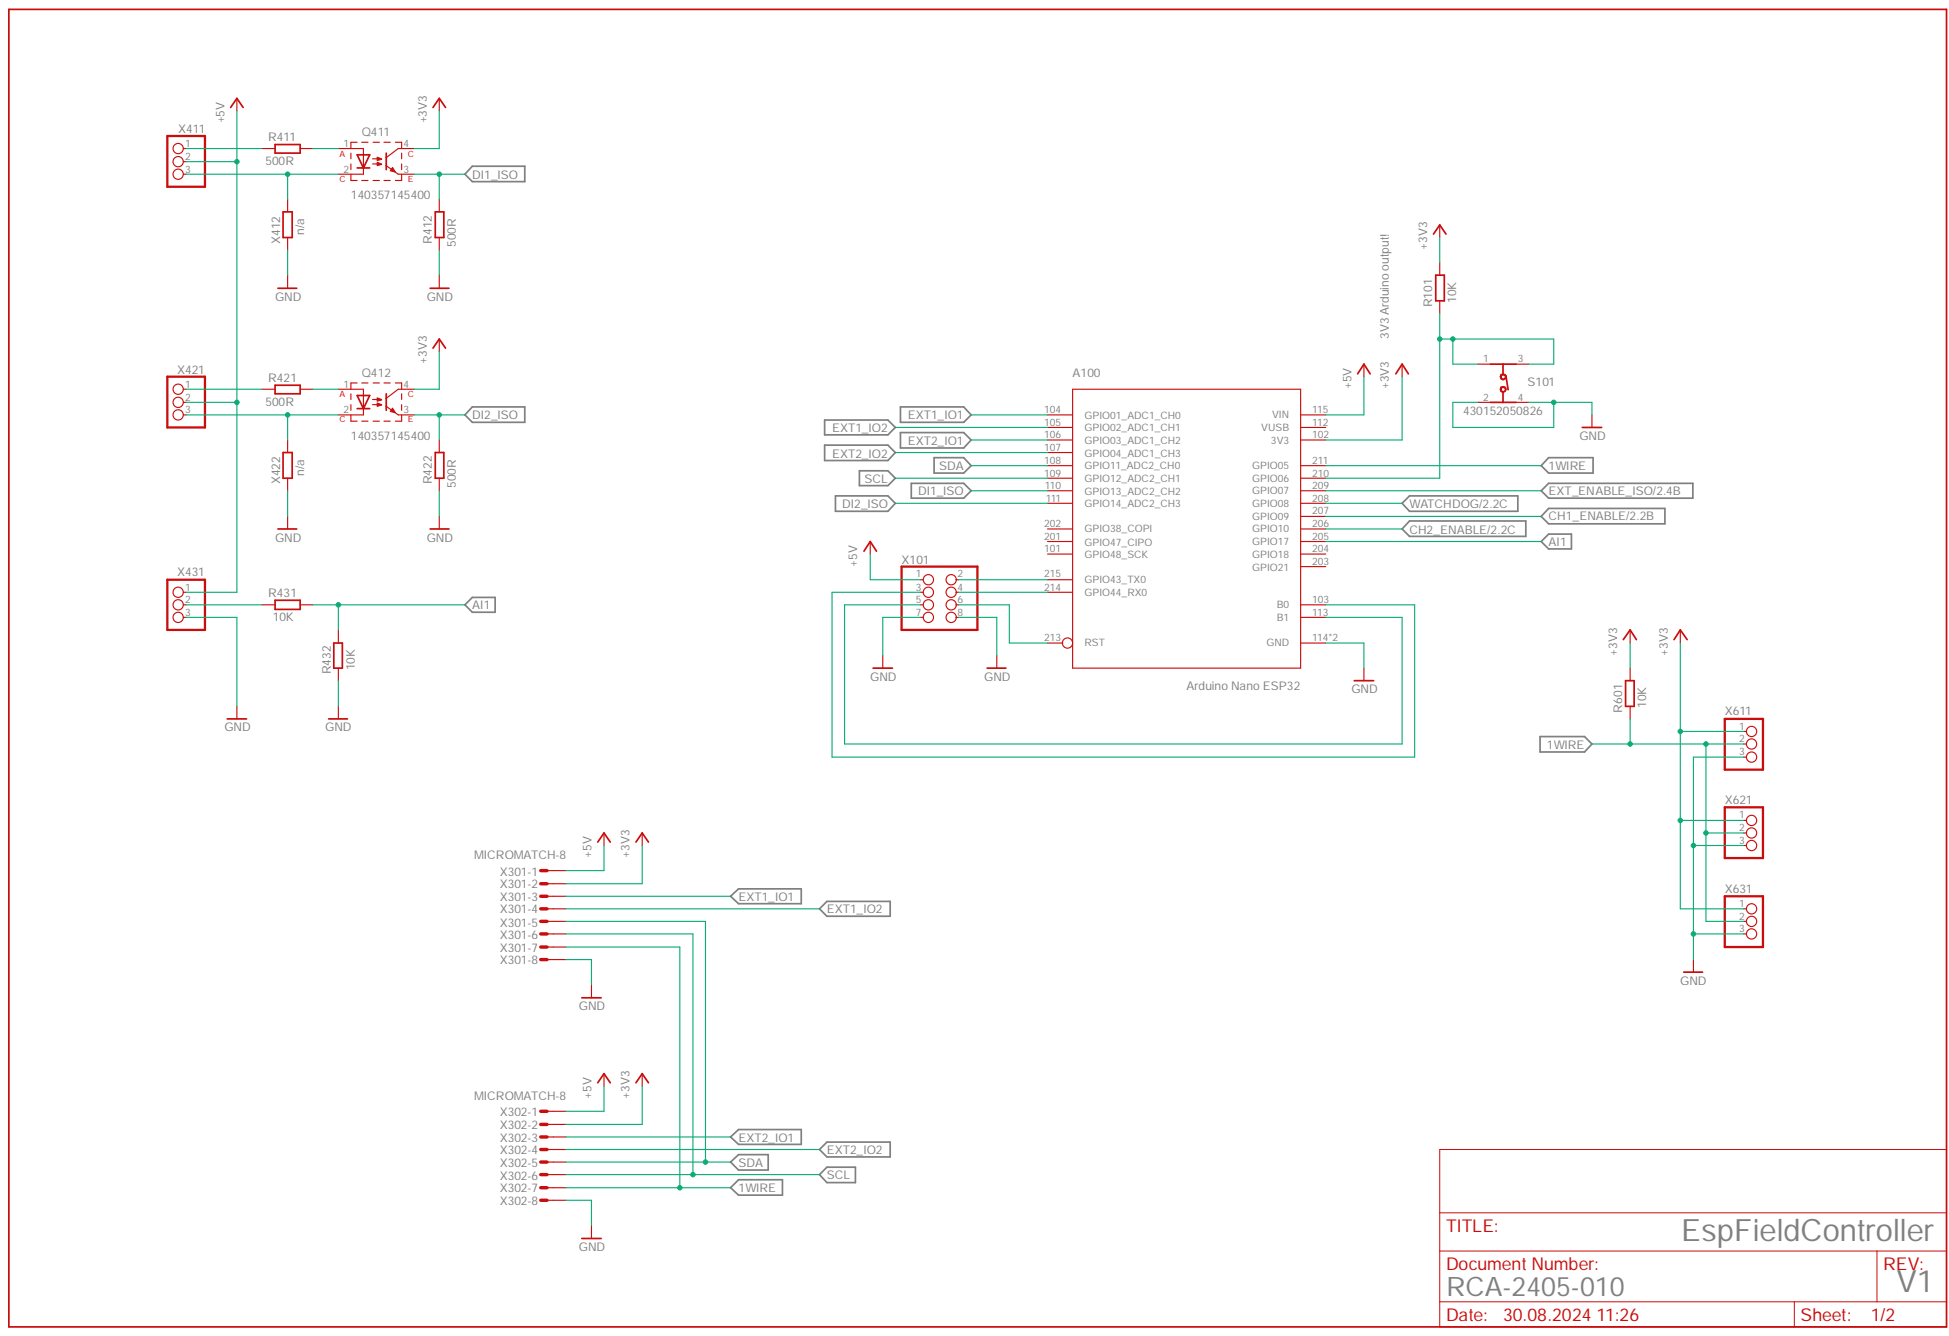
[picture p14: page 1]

Document Number: RCA-2405-010 | REV: V1

Date: 30.08.2024 11:26 | Sheet: 1/2

# GND ⁺⁵V

T200

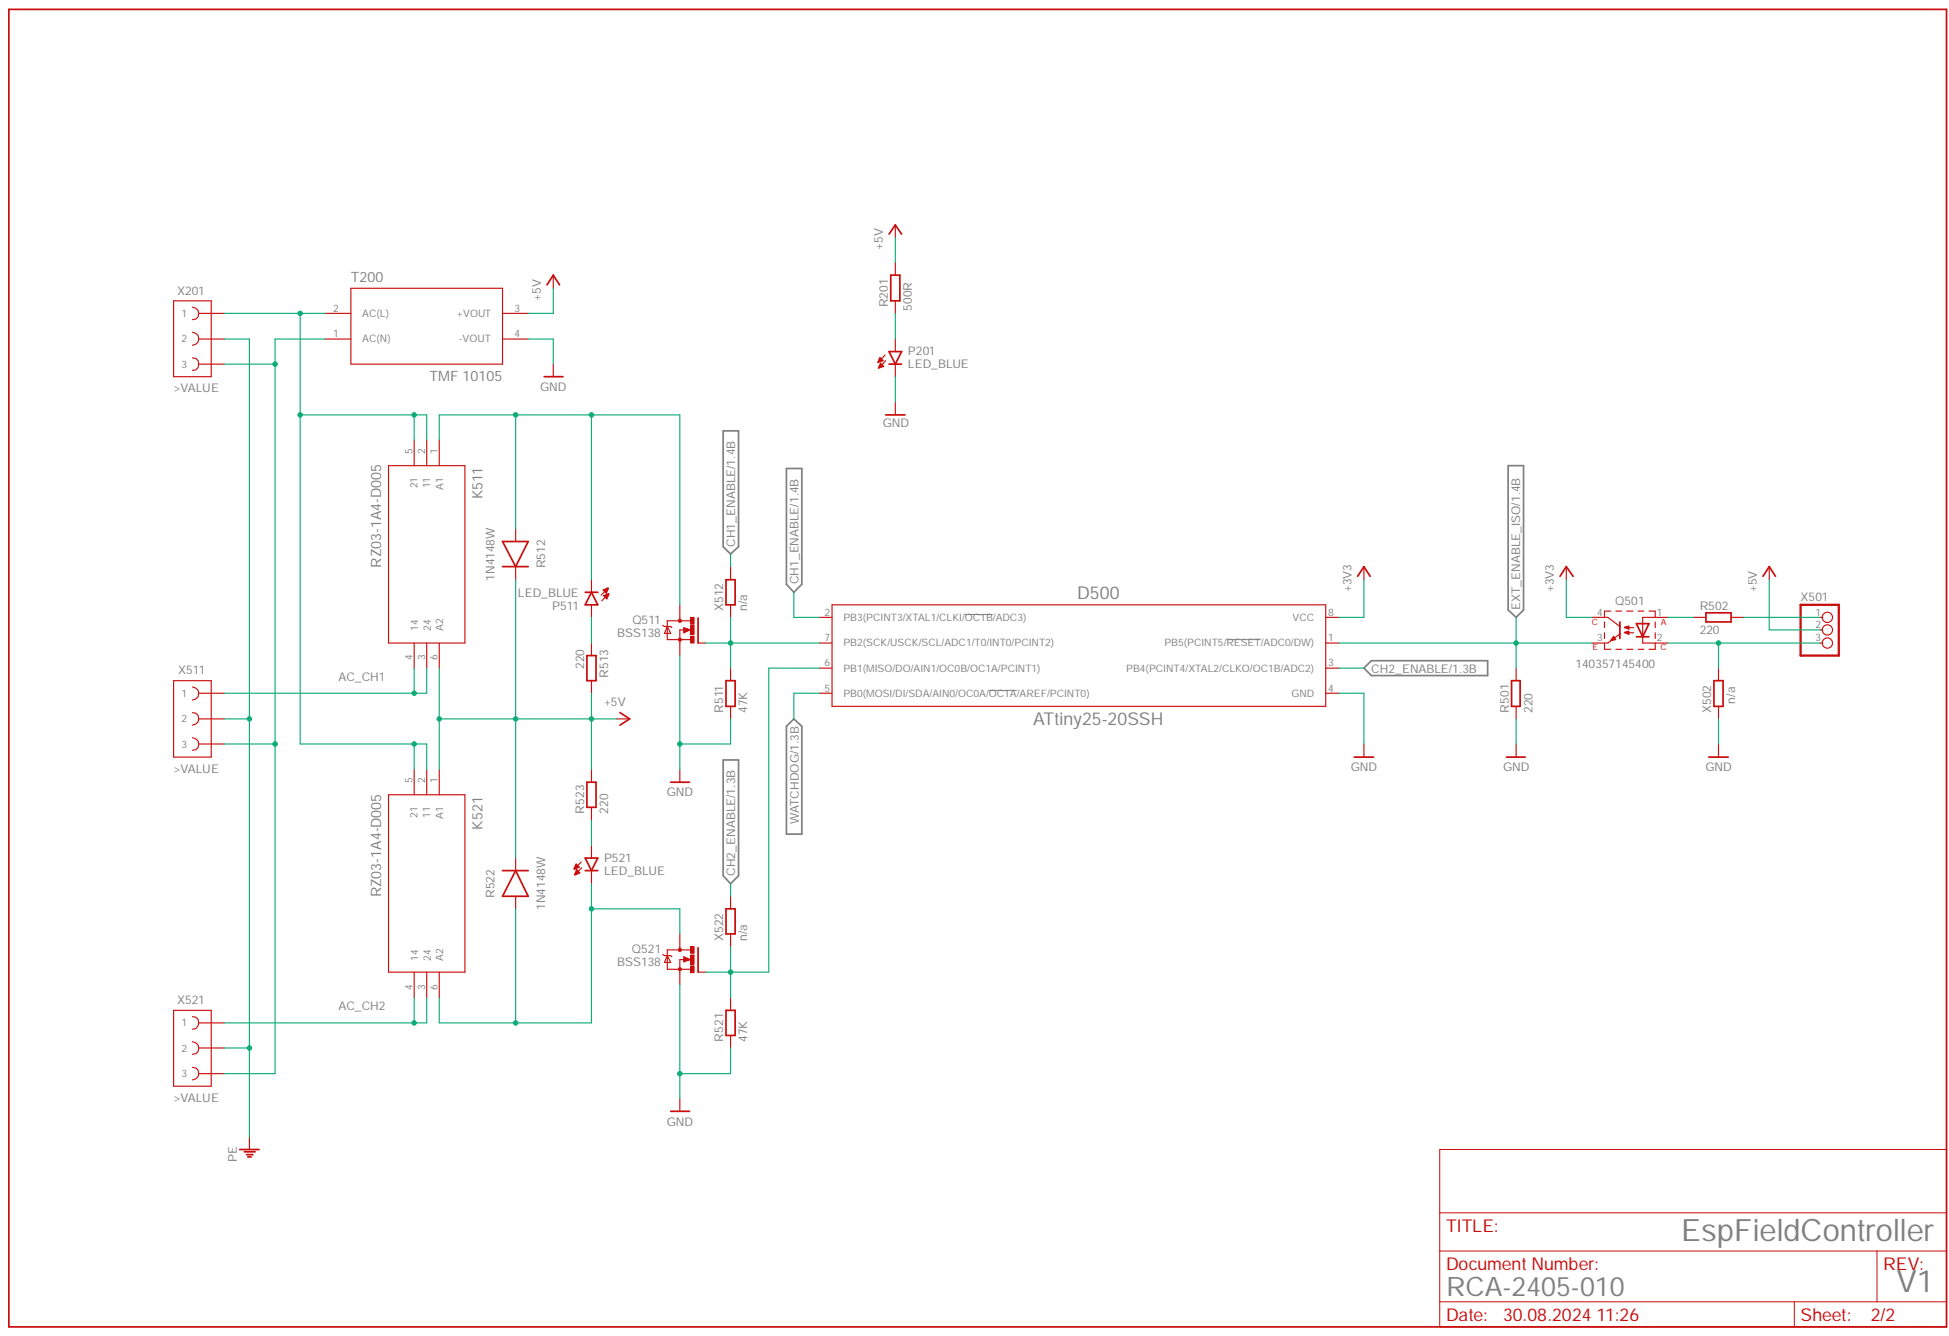
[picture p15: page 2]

PB0(MOSI/DI/SDA/AIN0/OC0A/OC1A/AREF/PCINT0) 5

Document Number: RCA-2405-010 | REV: V1

Date: 30.08.2024 11:26 | Sheet: 2/2

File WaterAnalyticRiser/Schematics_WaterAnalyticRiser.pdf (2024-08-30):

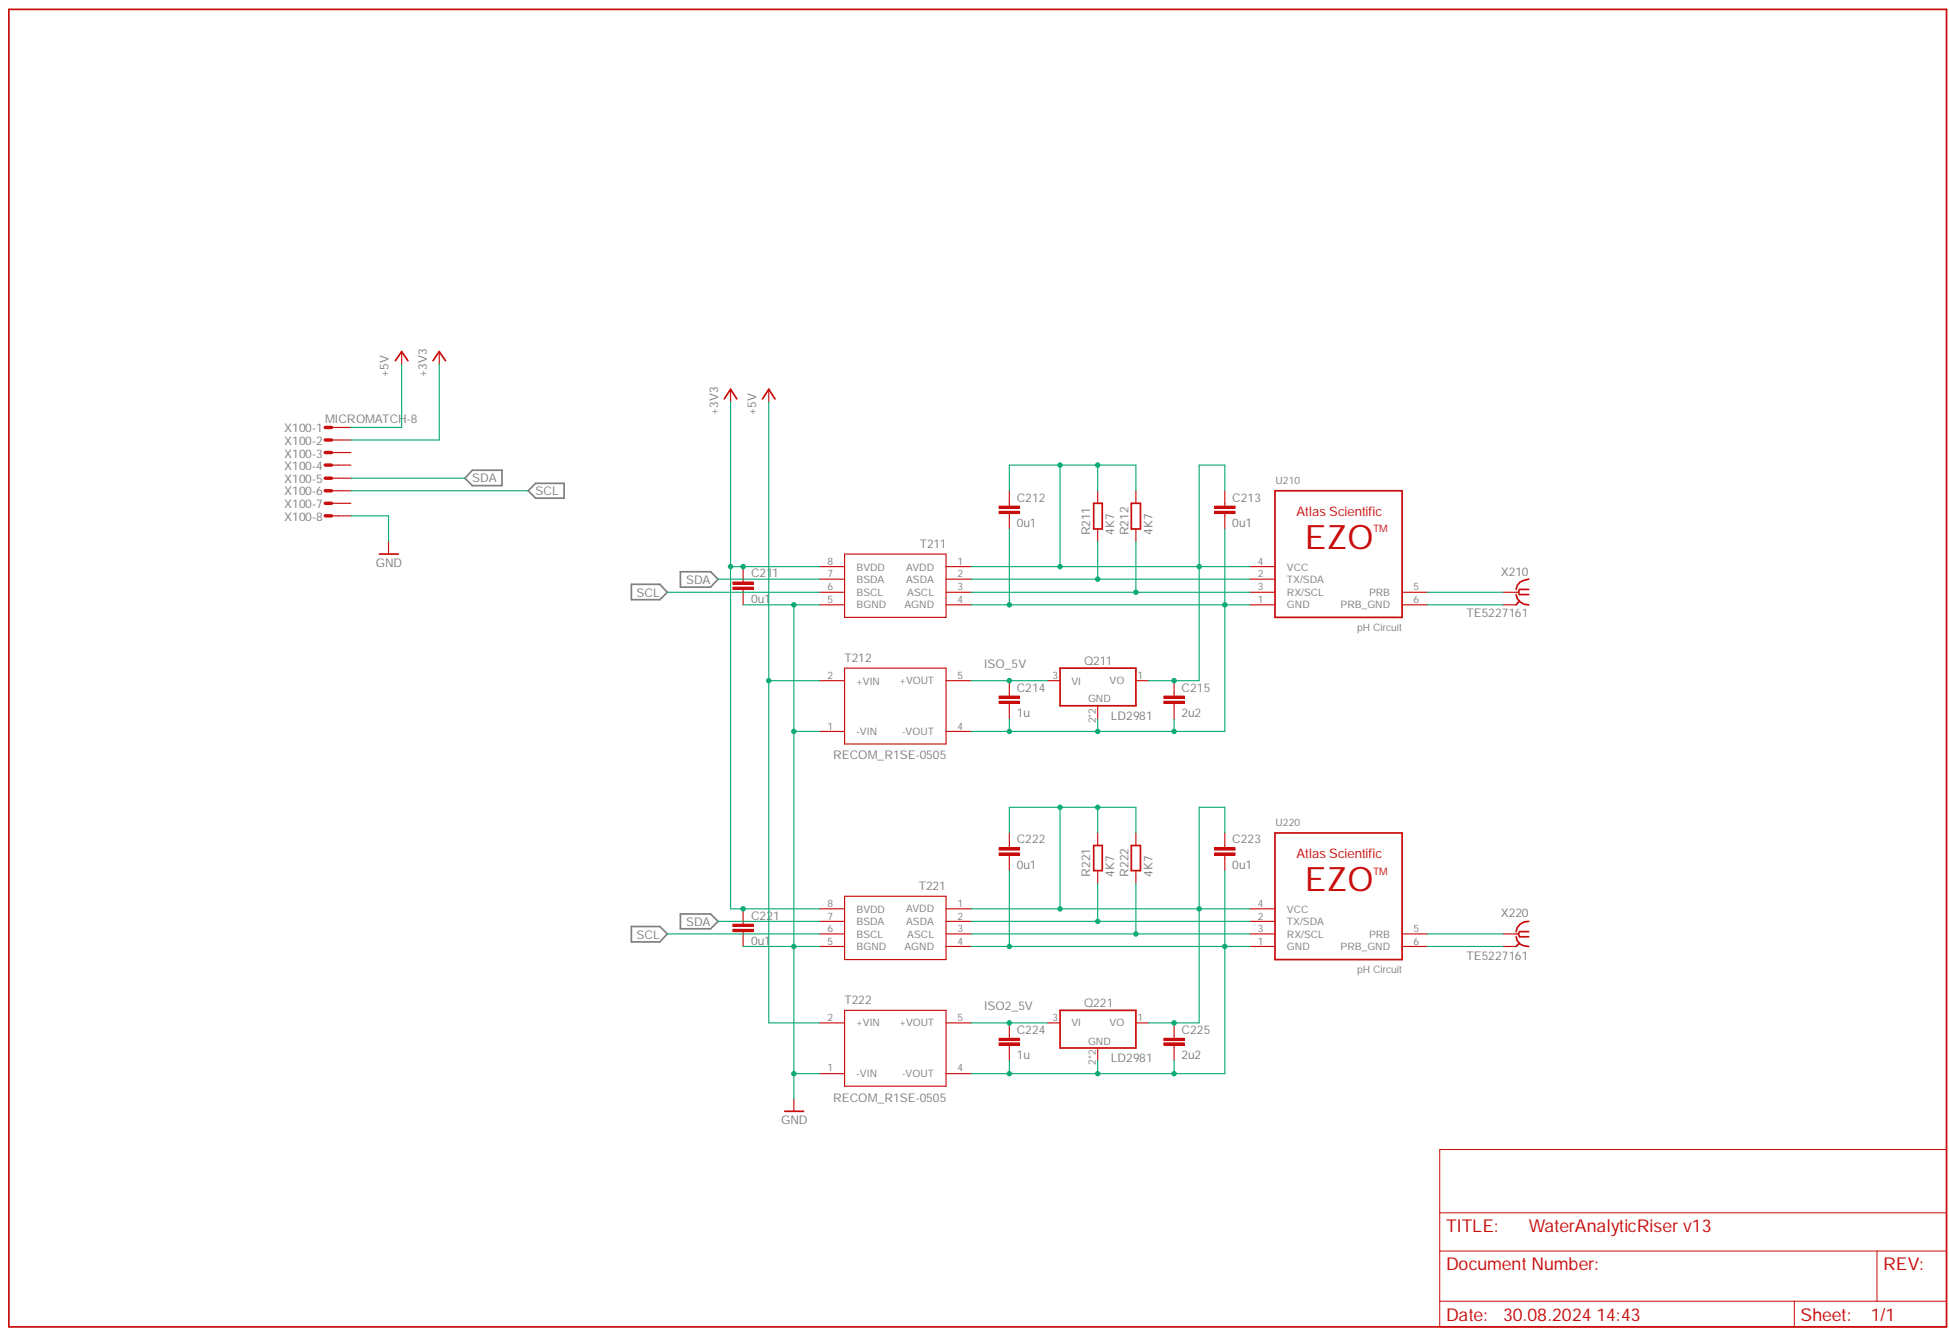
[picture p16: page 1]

Document Number: | REV:

Date: 30.08.2024 14:43 | Sheet: 1/1

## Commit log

2024-04-29 add cad images
2024-05-28 Add sch + bom
    [BOM_EspFieldController.csv, BOM_WaterAnalyticRiser.csv]
